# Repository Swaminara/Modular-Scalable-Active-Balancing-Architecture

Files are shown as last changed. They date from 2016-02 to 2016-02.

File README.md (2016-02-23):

# Modular-Scalable-Active-Balancing-Architecture

This repository contains the PCB design files of a modular scalable active cell balancing architecture proposed during my tenure as Research Associate in TUM CREATE. 

The PCBs are designed using Easily Accessible Graphical Layout Editor (EAGLE) 7.1.0 for windows. 
However, other versions of the software shall also be used for viewing and further modifying the design.

Scientific journals supporting the repository and explaining its working principle are submitted and under review process.

This repository is protected under the MIT license as attached in the repository.

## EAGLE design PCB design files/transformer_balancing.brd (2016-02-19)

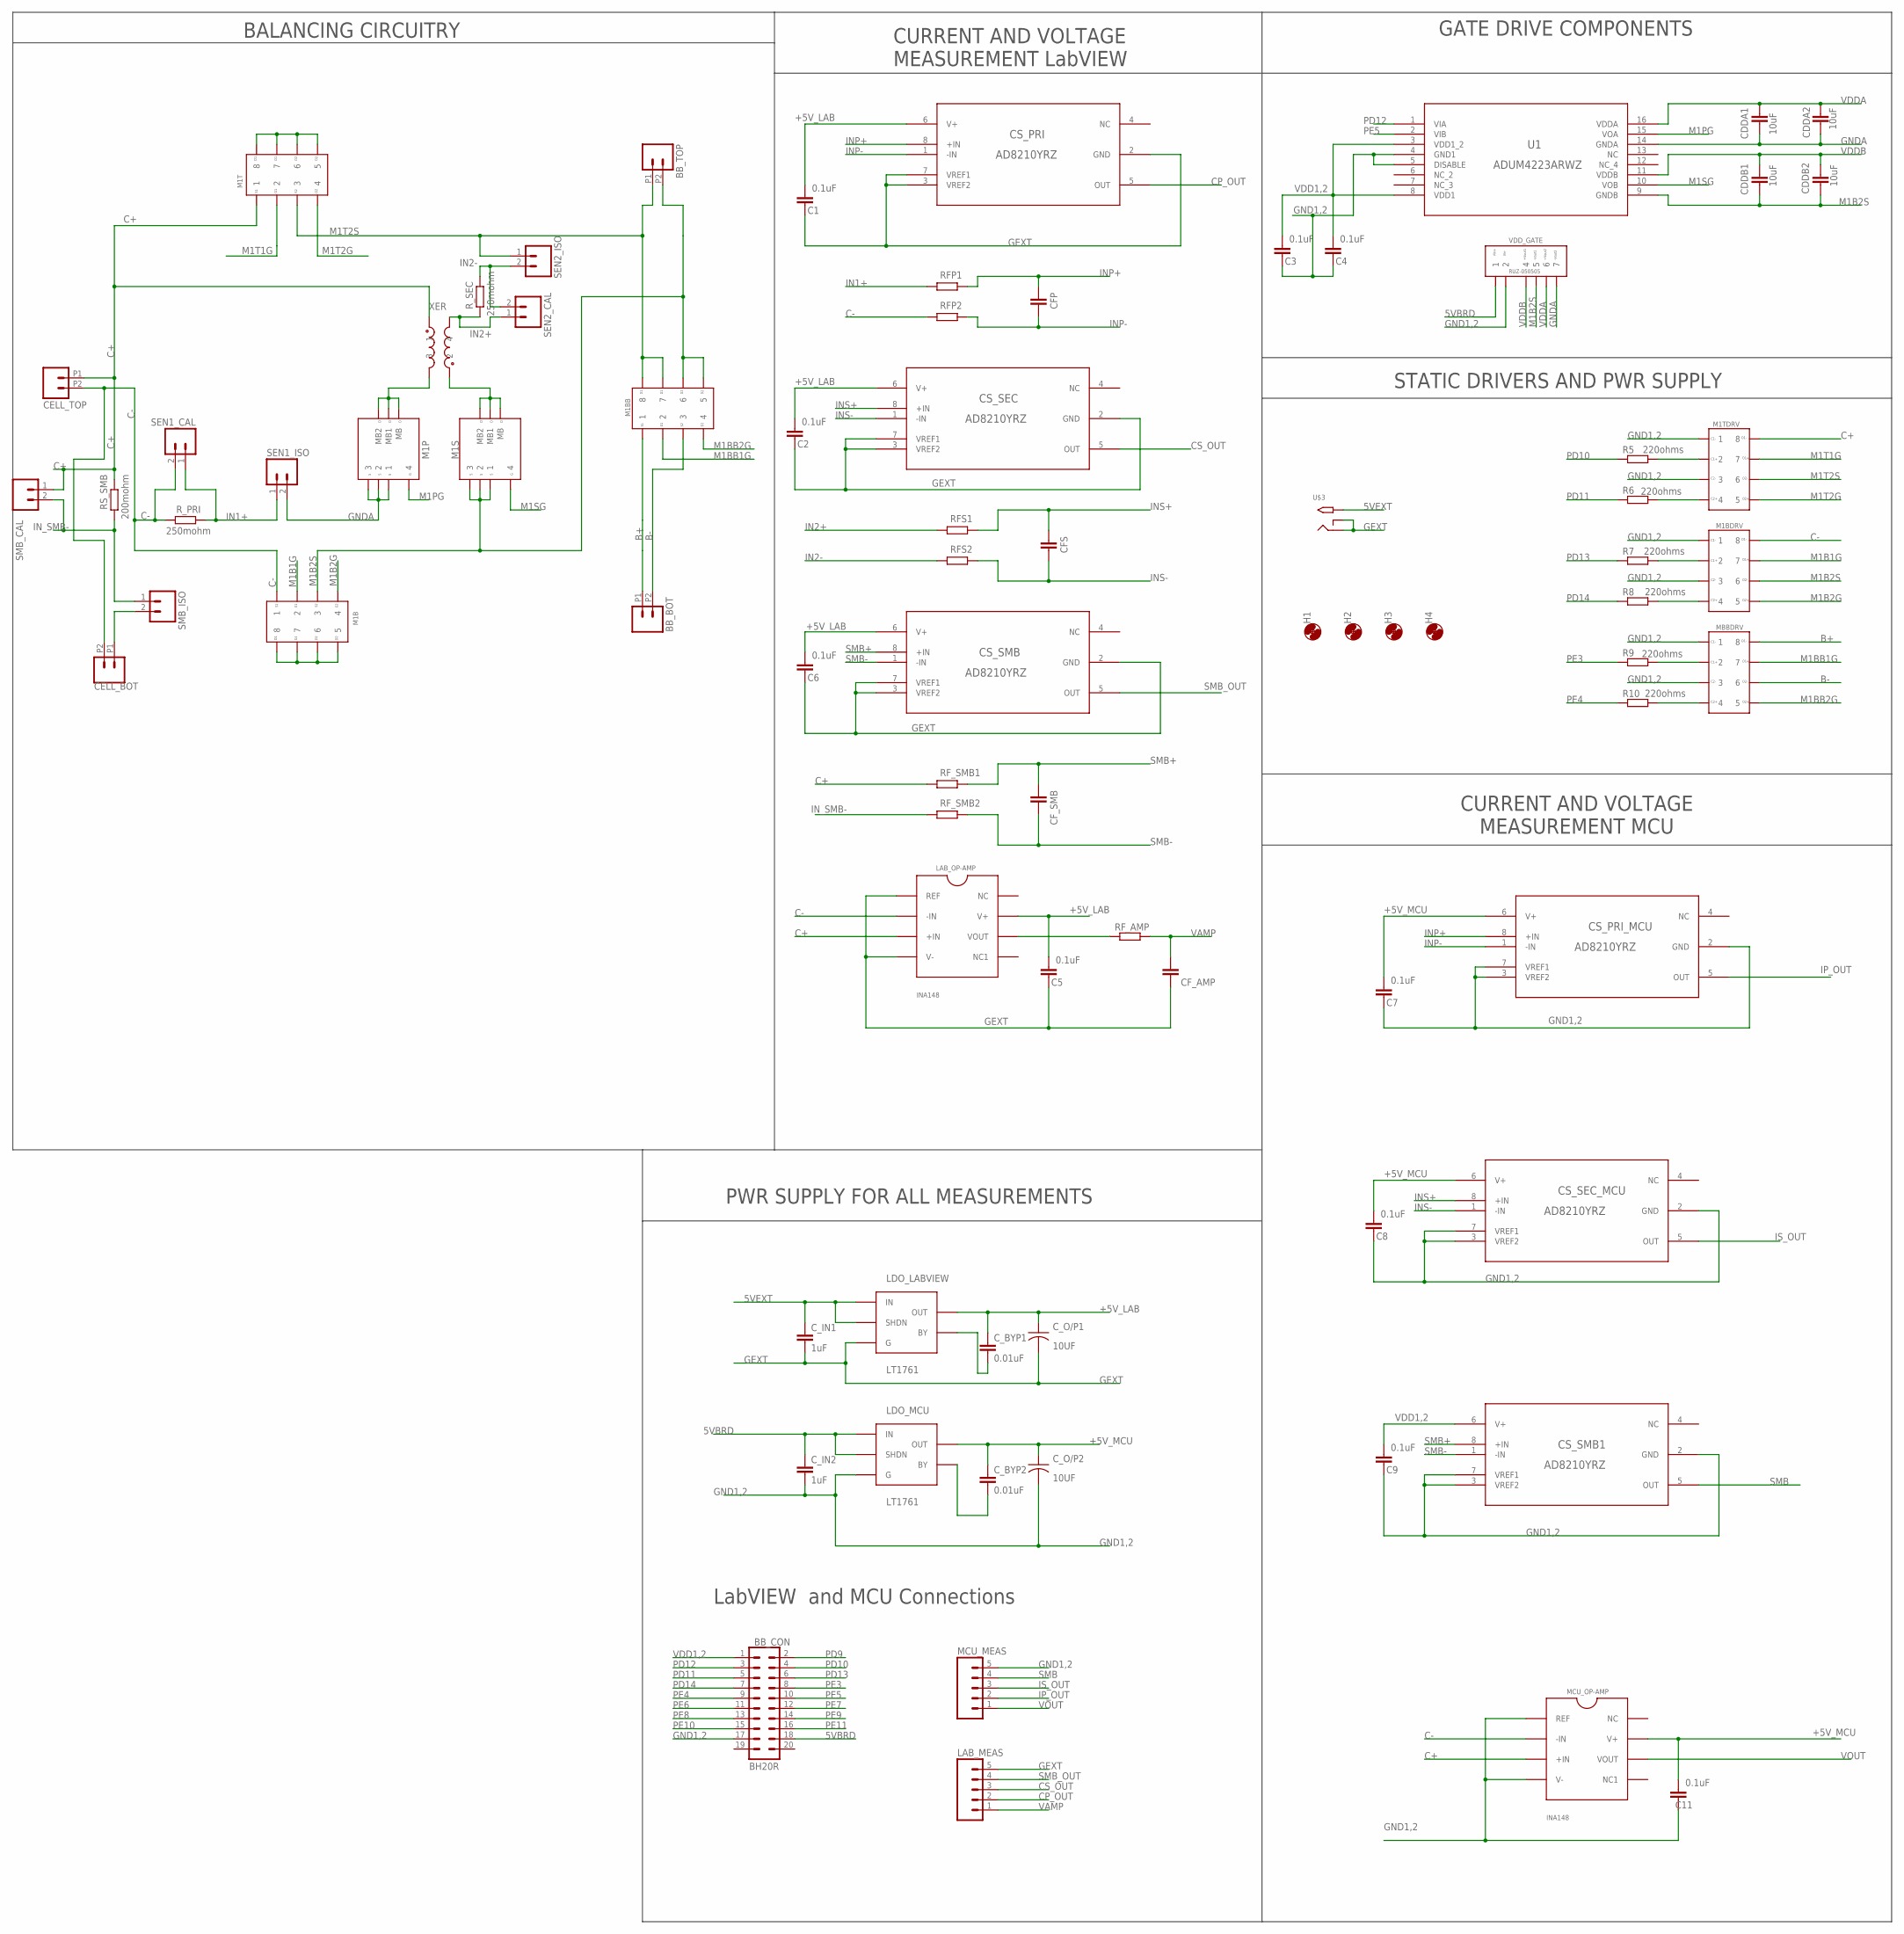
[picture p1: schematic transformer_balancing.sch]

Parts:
BB_BOT: M022.54MM_SCREWTERM; 1X02_2.54_SCREWTERM
BB_CON: BH20R
BB_TOP: M022.54MM_SCREWTERM; 1X02_2.54_SCREWTERM
C1, C2, C3, C4, C5, C6, C7, C8, C9, C11: 0.1uF; C0603
CDDA1, CDDA2: 10uF; C0603
CDDB1, CDDB2: 10uF; C0603
CELL_BOT: M022.54MM_SCREWTERM; 1X02_2.54_SCREWTERM
CELL_TOP: M022.54MM_SCREWTERM; 1X02_2.54_SCREWTERM
CFP: C-EUC0603; C0603
CFS: C-EUC0603; C0603
CF_AMP: C-EUC0603; C0603
CF_SMB: C-EUC0603; C0603
CS_PRI: AD8210YRZ; R_8
CS_PRI_MCU: AD8210YRZ; R_8
CS_SEC: AD8210YRZ; R_8
CS_SEC_MCU: AD8210YRZ; R_8
CS_SMB, CS_SMB1: AD8210YRZ; R_8
C_BYP1, C_BYP2: 0.01uF; C0402
C_IN1, C_IN2: 1uF; C0402
C_O/P1, C_O/P2: 10UF; 10UF_O/P_CAP_LDO
H1, H2, H3, H4: MOUNT-HOLE3.0; 3,0
LAB_MEAS: M05PTH; 1X05
LAB_OP-AMP: INA148
LDO_LABVIEW: LT1761
LDO_MCU: LT1761
M1B, M1BB, M1T: 2_CHANNEL_MOSFET
M1BDRV, M1TDRV: VOA1263
M1P, M1S: SWITCHING_MOSFET
MBBDRV: VOA1263
MCU_MEAS: M05PTH; 1X05
MCU_OP-AMP: INA148
R5, R6, R7, R8, R9, R10: 220ohms; R0603
RFP1, RFP2: 5R; R0603
RFS1, RFS2: 5R; R0603
RF_AMP: R-EU_R0603; R0603
RF_SMB1, RF_SMB2: 5R; R0603
RS_SMB: 200mohm; R0603
R_PRI: 250mohm; R0603
R_SEC: 250mohm; R0603
SEN1_CAL, SEN1_ISO, SEN2_CAL, SEN2_ISO: M02PTH; 1X02
SMB_CAL: M02PTH; 1X02
SMB_ISO: M02PTH; 1X02
U1: ADUM4223ARWZ; RW_16
U$3: 2.1MMJACK; PJ-102A
VDD_GATE: RUZ-050505
XER: COUPLED_INDUCTOR

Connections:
5VBRD: BB_CON.18, C_IN2.1, LDO_MCU.1 (IN), LDO_MCU.3 (SHDN), VDD_GATE.1
5VEXT: C_IN1.1, LDO_LABVIEW.1 (IN), LDO_LABVIEW.3 (SHDN), U$3.TIP
+5V_LAB: C1.1, C2.1, C5.1, C6.1, CS_PRI.6 (V+), CS_SEC.6 (V+), CS_SMB.6 (V+), C_BYP1.1, C_O/P1.1 (3), LAB_OP-AMP.V+, LDO_LABVIEW.5 (OUT)
+5V_MCU: C7.1, C8.1, C11.1, CS_PRI_MCU.6 (V+), CS_SEC_MCU.6 (V+), C_BYP2.1, C_O/P2.1 (3), LDO_MCU.5 (OUT), MCU_OP-AMP.V+
B+: BB_BOT.P1 (1), M1BB.1, MBBDRV.8
B-: BB_BOT.P2 (2), M1BB.3, MBBDRV.6
C+: CELL_TOP.P1 (1), LAB_OP-AMP.+IN, M1T.1, M1TDRV.8, MCU_OP-AMP.+IN, RF_SMB1.1, RS_SMB.1, SMB_CAL.1, XER.1
C-: CELL_BOT.P2 (2), CELL_TOP.P2 (2), LAB_OP-AMP.-IN, M1B.1, M1BDRV.8, MCU_OP-AMP.-IN, RFP2.1, R_PRI.2, SEN1_CAL.2
CP_OUT: CS_PRI.5 (OUT), LAB_MEAS.2
CS_OUT: CS_SEC.5 (OUT), LAB_MEAS.3
GEXT: C1.2, C2.2, C5.2, C6.2, CF_AMP.2, CS_PRI.2 (GND), CS_PRI.3 (VREF2), CS_PRI.7 (VREF1), CS_SEC.2 (GND), CS_SEC.3 (VREF2), CS_SEC.7 (VREF1), CS_SMB.2 (GND), CS_SMB.3 (VREF2), CS_SMB.7 (VREF1), C_IN1.2, C_O/P1.2 (4), LAB_MEAS.5, LAB_OP-AMP.REF, LAB_OP-AMP.V-, LDO_LABVIEW.2 (G), U$3.RING, U$3.RING_SW
GND1,2: BB_CON.17, C3.2, C4.2, C7.2, C8.2, C9.2, C11.2, CS_PRI_MCU.2 (GND), CS_PRI_MCU.3 (VREF2), CS_PRI_MCU.7 (VREF1), CS_SEC_MCU.2 (GND), CS_SEC_MCU.3 (VREF2), CS_SEC_MCU.7 (VREF1), CS_SMB1.2 (GND), CS_SMB1.3 (VREF2), CS_SMB1.7 (VREF1), C_IN2.2, C_O/P2.2 (4), LDO_MCU.2 (G), M1BDRV.1, M1BDRV.3, M1TDRV.1, M1TDRV.3, MBBDRV.1, MBBDRV.3, MCU_MEAS.5, MCU_OP-AMP.REF, MCU_OP-AMP.V-, U1.4 (GND1), U1.5 (DISABLE), VDD_GATE.2
GNDA: CDDA1.2, CDDA2.2, M1P.1, M1P.2, M1P.3, SEN1_ISO.2, U1.14 (GNDA), VDD_GATE.7
IN1+: RFP1.1, R_PRI.1, SEN1_CAL.1, SEN1_ISO.1
IN2+: RFS1.1, R_SEC.2, SEN2_CAL.1, XER.4
IN2-: RFS2.1, R_SEC.1, SEN2_CAL.2, SEN2_ISO.2
INP+: CFP.1, CS_PRI.8 (+IN), CS_PRI_MCU.8 (+IN), RFP1.2
INP-: CFP.2, CS_PRI.1 (-IN), CS_PRI_MCU.1 (-IN), RFP2.2
INS+: CFS.1, CS_SEC.8 (+IN), CS_SEC_MCU.8 (+IN), RFS1.2
INS-: CFS.2, CS_SEC.1 (-IN), CS_SEC_MCU.1 (-IN), RFS2.2
IN_SMB-: RF_SMB2.1, RS_SMB.2, SMB_CAL.2, SMB_ISO.1
IP_OUT: CS_PRI_MCU.5 (OUT), MCU_MEAS.2
IS_OUT: CS_SEC_MCU.5 (OUT), MCU_MEAS.3
M1B1G: M1B.2, M1BDRV.7
M1B2G: M1B.4, M1BDRV.5
M1B2S: BB_TOP.P2 (2), CDDB1.2, CDDB2.2, M1B.3, M1BB.5, M1BB.6, M1BDRV.6, M1S.1, M1S.2, M1S.3, U1.9 (GNDB), VDD_GATE.5
M1BB1G: M1BB.2, MBBDRV.7
M1BB2G: M1BB.4, MBBDRV.5
M1PG: M1P.4, U1.15 (VOA)
M1SG: M1S.4, U1.10 (VOB)
M1T1G: M1T.2, M1TDRV.7
M1T2G: M1T.4, M1TDRV.5
M1T2S: BB_TOP.P1 (1), M1BB.7, M1BB.8, M1T.3, M1TDRV.6, SEN2_ISO.1
unnamed: M1T.5, M1T.6, M1T.7, M1T.8
unnamed: M1TDRV.2, R5.2
unnamed: M1P.MB, M1P.MB1, M1P.MB2, XER.3
unnamed: M1TDRV.4, R6.2
unnamed: M1B.5, M1B.6, M1B.7, M1B.8
unnamed: MBBDRV.2, R9.2
unnamed: M1S.MB, M1S.MB1, M1S.MB2, XER.2
unnamed: MBBDRV.4, R10.2
unnamed: M1BDRV.4, R8.2
unnamed: LAB_OP-AMP.VOUT, RF_AMP.1
unnamed: M1BDRV.2, R7.2
unnamed: CELL_BOT.P1 (1), SMB_ISO.2
unnamed: C_BYP1.2, LDO_LABVIEW.4 (BY)
unnamed: C_BYP2.2, LDO_MCU.4 (BY)
PD9: BB_CON.2
PD10: BB_CON.4, R5.1
PD11: BB_CON.5, R6.1
PD12: BB_CON.3, U1.1 (VIA)
PD13: BB_CON.6, R7.1
PD14: BB_CON.7, R8.1
PE3: BB_CON.8, R9.1
PE4: BB_CON.9, R10.1
PE5: BB_CON.10, U1.2 (VIB)
PE6: BB_CON.11
PE7: BB_CON.12
PE8: BB_CON.13
PE9: BB_CON.14
PE10: BB_CON.15
PE11: BB_CON.16
SMB: CS_SMB1.5 (OUT), MCU_MEAS.4
SMB+: CF_SMB.1, CS_SMB.8 (+IN), CS_SMB1.8 (+IN), RF_SMB1.2
SMB-: CF_SMB.2, CS_SMB.1 (-IN), CS_SMB1.1 (-IN), RF_SMB2.2
SMB_OUT: CS_SMB.5 (OUT), LAB_MEAS.4
VAMP: CF_AMP.1, LAB_MEAS.1, RF_AMP.2
VDD1,2: BB_CON.1, C3.1, C4.1, C9.1, CS_SMB1.6 (V+), U1.3 (VDD1_2), U1.8 (VDD1)
VDDA: CDDA1.1, CDDA2.1, U1.16 (VDDA), VDD_GATE.6
VDDB: CDDB1.1, CDDB2.1, U1.11 (VDDB), VDD_GATE.4
VOUT: MCU_MEAS.1, MCU_OP-AMP.VOUT

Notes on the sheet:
BALANCING CIRCUITRY
CURRENT AND VOLTAGE MEASUREMENT LabVIEW
GATE DRIVE COMPONENTS
STATIC DRIVERS AND PWR SUPPLY
LabVIEW and MCU Connections
PWR SUPPLY FOR ALL MEASUREMENTS
CURRENT AND VOLTAGE MEASUREMENT MCU

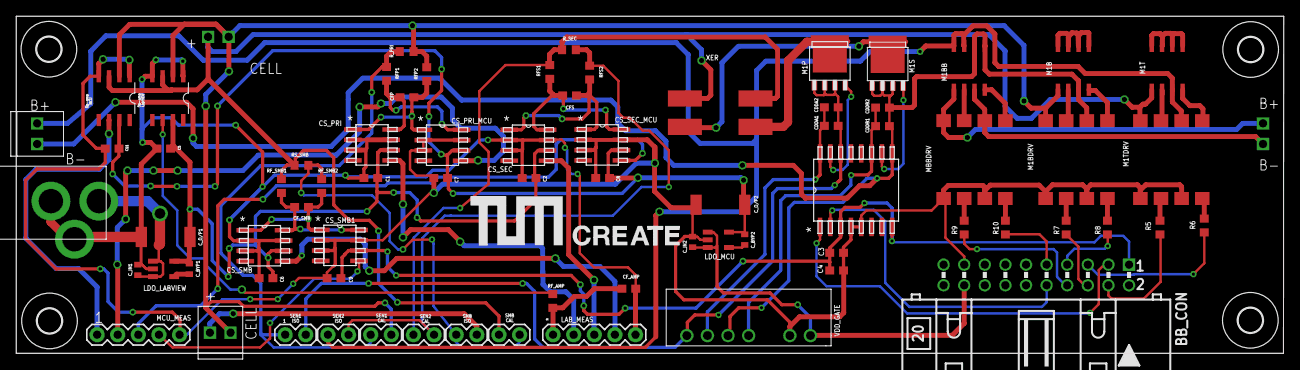
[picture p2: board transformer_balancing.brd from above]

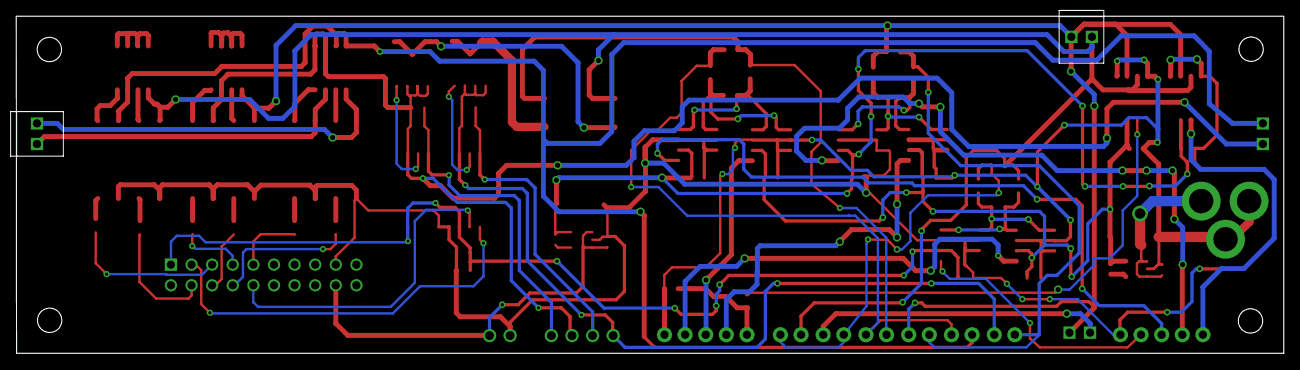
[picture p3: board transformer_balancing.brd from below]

Board: 2 copper layers, 156.2 x 41.5 mm, 80 parts (2 on the bottom side), 64 nets.

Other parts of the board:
U$1: BIGGER_LOGO

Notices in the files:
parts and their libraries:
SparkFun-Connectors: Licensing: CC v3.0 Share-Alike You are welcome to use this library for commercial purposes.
